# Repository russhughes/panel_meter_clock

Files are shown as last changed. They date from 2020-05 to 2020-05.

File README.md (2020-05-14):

Panel Meter Clock V2.1
----------------------
My father has been a lifelong Ham Radio Operator with a fondness for anything
with a panel meter. After seeing the [“Trinket Powered Analog Meter
Clock”](<https://learn.adafruit.com/trinket-powered-analog-meter-clock>) by
Mike and Anne Barela on the Adafruit website I knew I had to make one like it
to give to my Dad for his 80th birthday.

Here is Version 2.1 of that clock.

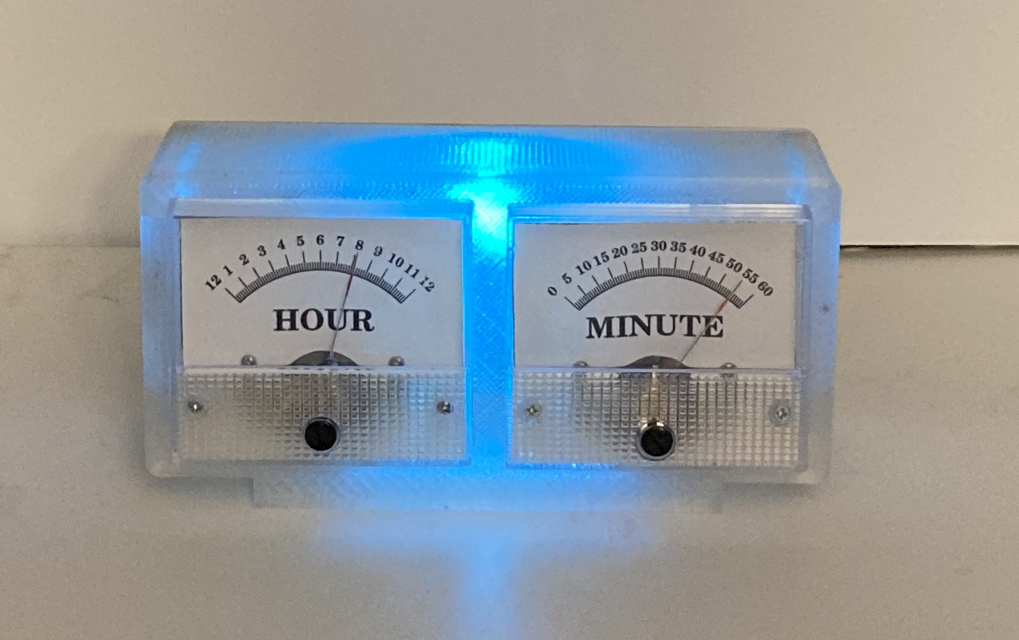
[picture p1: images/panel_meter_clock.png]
Panel Meter Clock


3D Printed Case
---------------
All parts print without support. I have printed them with 0.3mm or
0.2mm layer heights using 3 top, bottom and perimeter shells in PLA.

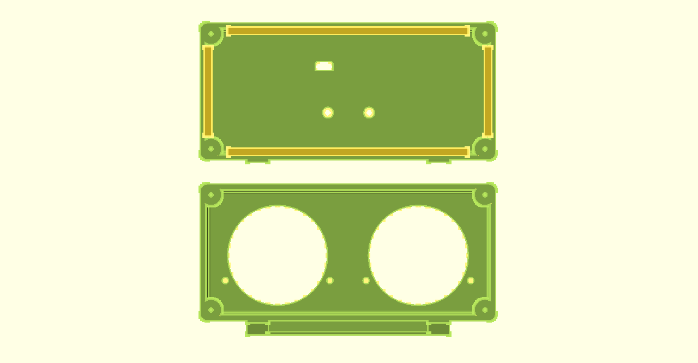
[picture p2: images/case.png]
Case


Meter Faces
-----------
The Hour and Minute meter scales were created using Inkscape. The source SVG
file is provided in case you wish to make changes, as well as 300 and 600dpi
PDF files that can be printed at 100% scale.

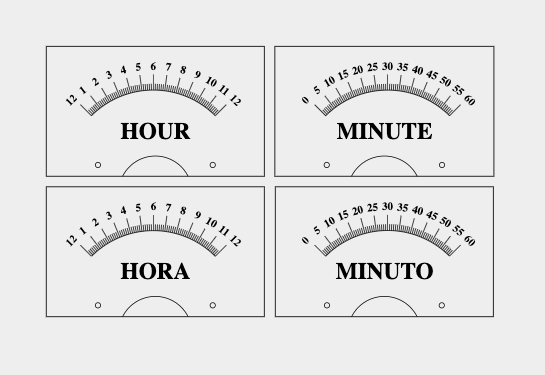
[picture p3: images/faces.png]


PC Board
--------
I designed a custom Arduino Leonardo compatible P.C. board with a DS321 RTC
clock, NeoPixel and USB connector that mounts directly to the back of the two
panel meters.

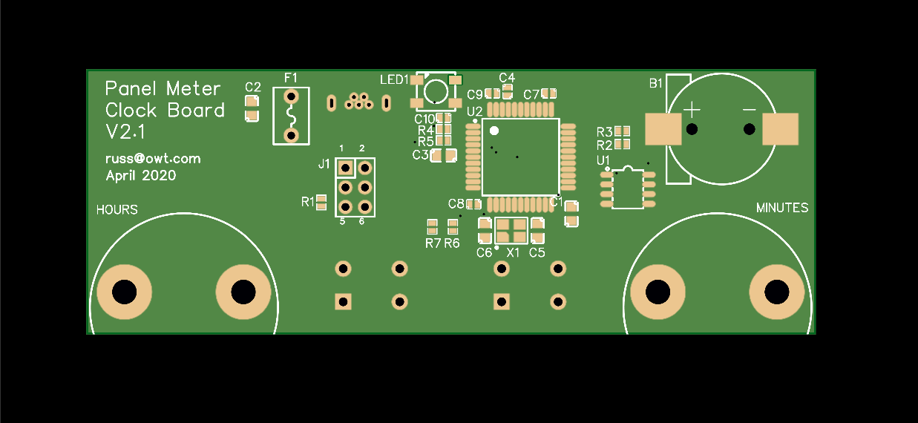
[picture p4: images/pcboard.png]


Additional Information
----------------------

[Assembly Video](https://youtu.be/PN79dx3BKjI)

[Assembly Instructions](http://penfold.owt.com/panel_meter_clock_v2.1)

[GitHub Repo](https://github.com/russhughes/panel_meter_clock)

Additional Arduino Libraries
----------------------------

- [Adafruit RTClib](https://github.com/adafruit/RTClib)
- [Adafruit NeoPixel](https://github.com/adafruit/Adafruit_NeoPixel)

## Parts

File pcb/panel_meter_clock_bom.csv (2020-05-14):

ID | Name | Designator | Footprint | Quantity | Manufacturer Part | Manufacturer | Supplier | Supplier Part | LCSC Assembly
1 | MINUTE_ADJ | MINUTE | SW4-6.0X6.0X5.0MM | 1 | TS-1109 |  | SeeedStudio | 311020024
2 | HOUR_ADJ | HOUR | SW4-6.0X6.0X5.0MM | 1 | TS-1109 |  | SeeedStudio | 311020024
3 | 22 | R5,R4 | R0402 | 2 | 0402WGF220JTCE | UniOhm | LCSC | C25092 | Yes
4 | 22pF | C6,C5 | C0603 | 2 | CL10C220JB8NNNC | SAMSUNG | LCSC | C1653 | Yes
5 | ATMEGA32U4-AU | U2 | QFP-44_L10.0-W10.0-P0.80-LS13.2-BL | 1 | ATMEGA32U4-AU | MICROCHIP | LCSC | C44854 | Yes
6 | DS3231MZ+ | U1 | SOIC-8_L4.9-W3.9-P1.27-LS6.0-BL | 1 | DS3231MZ+ | MAXIM | LCSC | C107410 | Yes
7 | 10uF | C2 | C0603 | 1 | CL10A106KP8NNNC | SAMSUNG | LCSC | C19702 | Yes
8 | WS2812B-B | LED1 | LED-SMD_4P-L5.0-W5.0-BL | 1 | WS2812B-B | Worldsemi | LCSC | C114586 | Yes
9 | 10K | R7,R6,R3,R2,R1 | R0402 | 5 | 0402WGF1002TCE | UniOhm | LCSC | C25744 | Yes
10 | ICSP | J1 | HEADER_PRG_2X03 | 1
11 | Voltmeter_DC | HOURS,MINUTES | 85C1 SERIES PANEL METER | 2
12 | micro 5P180 | USB | MICRO-USB-TH_U-MICRS05P-BF00 | 1 | micro 5P180 | ValuePro | LCSC | C40941
13 | TRC025 | F1 | FUSE-TH_L7.4-W4.6-P5.10-D0.6 | 1 | TRC025 | TLC Electronic | LCSC | C262081
14 | CR1220-2 | B1 | BAT-SMD_CR1220-2 | 1 | CR1220-2 | Q&J | LCSC | C70381
15 | 1uF | C1,C3 | C0603 | 2 | CL10A105KB8NNNC | SAMSUNG | LCSC | C15849 | Yes
16 | 100nF | C4,C9,C7,C10,C8 | C0402 | 5 | CL05B104KO5NNNC | SAMSUNG | LCSC | C1525 | Yes
17 | 16MHz | X1 | OSC-SMD_4P-L3.2-W2.5-BL | 1 | 7M1604LCSC-EEQ4S | TXC | LCSC | C90905 | Yes

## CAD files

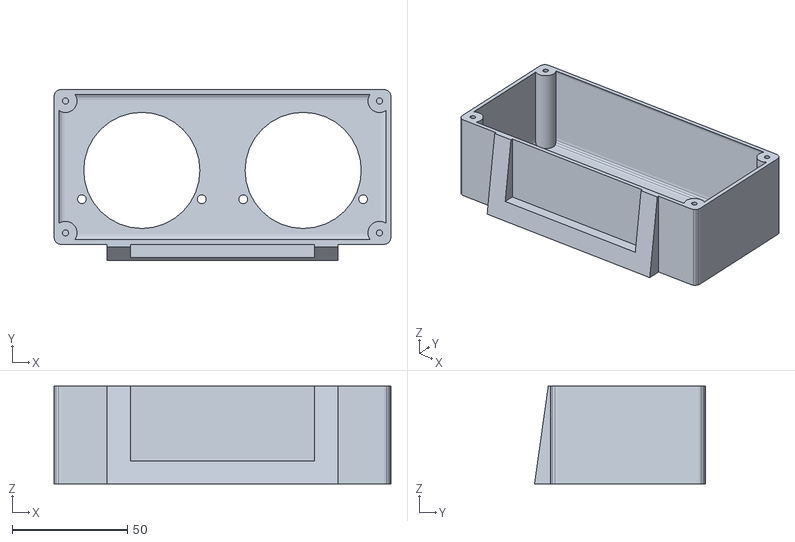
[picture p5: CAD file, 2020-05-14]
stl_files/panel_meter_clock_front.stl
146.2 x 74.2 x 42.4

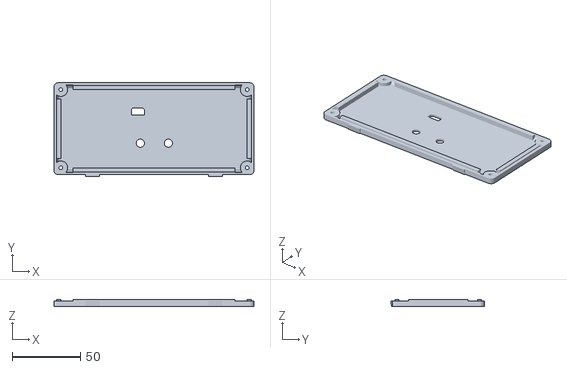
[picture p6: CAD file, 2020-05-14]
stl_files/panel_meter_clock_back.stl
146.2 x 68.4 x 5.00

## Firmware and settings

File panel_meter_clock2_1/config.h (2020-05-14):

//
// Panel Meter Clock by Russ Hughes (russ@owt.com)
// April 2020
//
//
// Shared under the Creative Commons - Attribution - ShareAlike 3.0 license.
//

#ifndef __CONFIG_H__
#define __CONFIG_H__

// define pins usage

#define HOURPWM 5
#define MINPWM  6
#define HOURADJ 8
#define MINADJ 11
#define NEOPIXEL 10

// EEPROM config value offsets

#define EEPROM_SENTINEL 0
#define EEPROM_HOURS_CAL 3
#define EEPROM_MINUTES_CAL 16
#define EEPROM_COLOR_MODE 138
#define EEPROM_GLOB_SCALE 139
#define EEPROM_GMT_OFFSET 140
#define EEPROM_DST_OBS 141
#define EEPROM_NEOPIXEL_R 142
#define EEPROM_NEOPIXEL_G 143
#define EEPROM_NEOPIXEL_B 144
#define EEPROM_LATITUDE 145
#define EEPROM_LONGITUDE 155
#define EEPROM_AVAIL 165

// colorModes

#define MODE_NONE 0
#define MODE_FIXED 1
#define MODE_WHEEL 2
#define MODE_SKY 3
#define MODE_SUN 4

//
// BEGIN DEFAULT CONFIG VALUES
//

#define DEFAULT_COLOR_MODE MODE_WHEEL
#define DEFAULT_GMT_OFFSET -8
#define DEFAULT_DST_OBSERVED 1
#define DEFAULT_LATITUDE "46.2087"
#define DEFAULT_LONGITUDE "-119.1199"
#define DEFAULT_R 32
#define DEFAULT_G 0
#define DEFAULT_B 0

//
// END DEFAULT CONFIG VALUES
//

#define MAX_LOC_LEN 10

extern char aLatitude[MAX_LOC_LEN+1];
extern char aLongitude[MAX_LOC_LEN+1];

extern uint8_t HOURS_CAL[13];
extern uint16_t MINUTES_CAL[61];
extern uint8_t colorMode;
extern uint8_t globScale;
extern int8_t gmtOffset;
extern uint8_t dstObs;
extern float longitude;
extern float latitude;

extern int dstActive;
extern int lastDay;
extern int lastHour;
extern int lastMinute;
extern int colorStep;
extern uint8_t r, g, b;

extern float sky_angle;
extern DateTime theTime;

extern Adafruit_NeoPixel pixel;
extern RTC_DS3231 rtc;

void configCreate();
void configLoad();
void configMenu();

extern int isDST(int day, int month, int dow);
extern DateTime now(void);

extern void setColor(uint32_t color);
extern uint32_t Wheel(byte WheelPos);
extern void setPixelColor(float sky_angle, uint8_t glob_scale);

#endif

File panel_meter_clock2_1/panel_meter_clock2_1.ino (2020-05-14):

//
// Panel Meter Clock by Russ Hughes (russ@owt.com)
// April 2020
//
// Shared under the Creative Commons - Attribution - ShareAlike 3.0 license.
//

#include <avr/pgmspace.h>
#include <EEPROM.h>
#include <RTClib.h>
#include <Adafruit_NeoPixel.h>
#include <stdint.h>
#include <math.h>

#include "config.h"

int dosetdate = 0;	// set to 1 to always set date/time to compiled time.

//
// Solar Calculations based on formulas from the NOAA Sunrise/Sunset and Solar Position
// Calculator Excel spreadsheet availabe from:
//
// https://www.esrl.noaa.gov/gmd/grad/solcalc/NOAA_Solar_Calculations_day.xls
//

#include "sun.h"

/*
 * colourcalc.h
 *
 * Created: 19/10/2016 15:06:02
 *  Author: David Brown
 * Shared under the Creative Commons - Attribution - ShareAlike 3.0 license.
 */

#include "colourcalc.h"
perez colour;

// Prototypes
float level(float in);

// Globals

float sky_angle = 1.309;
float theta_max;
float theta_sun;
float scalar = 3;
float turbidity = 1.8;

int dstActive = 0;
int	lastDay = -1;
int lastHour = -1;
int lastMinute = -1;
int colorStep = 0;

Adafruit_NeoPixel pixel = Adafruit_NeoPixel(1, NEOPIXEL, NEO_GRB + NEO_KHZ800);
RTC_DS3231 rtc;

//
// Returns 1 if DST should be active today
//

int isDST(int day, int month, int dow) {
   if (month < 3 || month > 11) {
      return 0;
   }
   if (month > 3 && month < 11) {
      return 1;
   }
   int previousSunday = day - dow;
   if (month == 3) {
      return previousSunday >= 8;
   }
   return previousSunday <= 0;
}

//
// Returns the current time as a DateTime object adjusting for
// US daylight saving time as needed if dstObs is set to a true value
//

DateTime now(void) {

    // get the time from the RTC
    DateTime theTime = rtc.now();

    // check if DST is observed in this location
    if (dstObs) {
        // check if DST should be in effect today
        if (isDST(theTime.day(), theTime.month(), theTime.dayOfTheWeek())) {
            // if DST is not currently active & it is after 02:00
            if (!dstActive && theTime.hour() >= 2)
                dstActive = 1;          // make DST active
        } else {
            // if DST is currently active & it is after 02:00
        if (dstActive && theTime.hour() >= 2)
            dstActive = 0;  // make DST not active
        }
    } else {
		dstActive = 0;	// DST not observed so not active
	}

	// if DST is active spring forward one hour
    if (dstActive)
        return theTime + TimeSpan(0, 1, 0, 0);

	// DST is not active use RTC time directly
	return theTime;
}

//
// Calculates the solar max using the height of the sun
// in radians at solar noon for the current day.
//

float calcSolarMax() {
	int solarNoonHour;
	int solarNoonMinute;

	theTime = now();
	float solarNoon = calcSolarNoon(
		latitude,
		longitude,
		theTime.year(),
		theTime.month(),
		theTime.day(),
		gmtOffset
	);

	decToHourMinute(solarNoon, &solarNoonHour, &solarNoonMinute);

	return radians(
		calcSolarZenithAngle(
			latitude,
			longitude,
			theTime.year(),
			theTime.month(),
			theTime.day(),
			solarNoonHour,
			solarNoonMinute,
			gmtOffset
		)
	);
}

//
// Setup IO pins, PWN, RTC and NeoPixel.
//

void setup() {
    Serial.begin(9600);

	// Check EEPROM for calibration data

	if (EEPROM[EEPROM_SENTINEL] != 'P' && EEPROM[EEPROM_SENTINEL+1] != 'M' &&EEPROM[EEPROM_SENTINEL+2] != 'C') {
		configCreate();
	}

	//configCreate();  // uncomment to override EEPROM settings with defaults
	configLoad();

    pinMode(HOURPWM, OUTPUT);	// hour pwm pin
    pinMode(MINPWM, OUTPUT);	// minute pwm pin
    pinMode(HOURADJ, INPUT);	// hour adjust pin
    pinMode(MINADJ, INPUT);		// minute adjust pin

	//
	// Set D6 to 10 bit PWM
	//

    TCCR4E |= (1<<ENHC4);
    TCCR4B &= ~(1<<CS41);
    TCCR4B |= (1<<CS42)|(1<<CS40);
    TCCR4D |= (1<<WGM40);
    TC4H = 0x3;
    OCR4C = 0xFF;
    TCCR4C |= (1<<COM4D1)|(1<<PWM4D);

	//
    // Start the clock
	//

    if (! rtc.begin()) {
		while(1) {
        	Serial.println(F("Could not find RTC!"));
			delay(1000);
		}
    }

	//
	// if the RTC lost power set the RTC to the date & time this sketch was compiled
	//

    if (dosetdate || rtc.lostPower()) {
        Serial.println(F("RTC was NOT running!"));
        rtc.adjust(DateTime(F(__DATE__), F(__TIME__)));
    }

	//
	// Get the solar max for today
	//

	theta_max = calcSolarMax();

	//
	// Start the NeoPixel
	//

    pixel.begin();
	if (colorMode == MODE_FIXED) {
		pixel.setPixelColor(0, pixel.Color(r, g, b));
		pixel.show();
	}

	//
	// Initialize the color class & coefficients
	//

	colour.generate_perez_coeff(turbidity);
}

//
//	Update minute meter 10 bit PWM
//

void updateMinute(uint16_t value) {
	TC4H = value>>8;
    OCR4D = (value&0xFF);
}

//
//  Sets the NeoPixel color
//

void setColor(uint32_t color) {
   	pixel.setPixelColor(0, color);
   	pixel.show();
}

//
// Return the color for the given WheelPos
//

uint32_t Wheel(byte WheelPos) {
    WheelPos = 255 - WheelPos;
    if (WheelPos < 85) {
        return pixel.Color(255 - WheelPos * 3, 0, WheelPos * 3);
    }
    if (WheelPos < 170) {
        WheelPos -= 85;
        return pixel.Color(0, WheelPos * 3, 255 - WheelPos * 3);
    }
    WheelPos -= 170;
    return pixel.Color(WheelPos * 3, 255 - WheelPos * 3, 0);
}

//
// Main Loop
//

void loop() {

	int day;
    int	hour;
    int minute;

	//
	//	Bring up the configure menu if the
	//	escape key is pressed
	//

	if (Serial.available()) {
		char ch = Serial.read();
		if (ch == 27)
			configMenu();
	}

	//
	//	Advance the hour if the hour adjust button
	// 	is pressed and released
	//

    if (digitalRead(HOURADJ) == LOW)  {
        while (digitalRead(HOURADJ) == LOW)
            delay(50);

        rtc.adjust(rtc.now() + TimeSpan(0, 1, 0, 0));
    }

	//
	//	Advance the minute if the minute adjust button
	// 	is pressed and released
	//

    if (digitalRead(MINADJ) == LOW)  {
        while (digitalRead(MINADJ) == LOW)
            delay(50);

        rtc.adjust(rtc.now() + TimeSpan(0, 0, 1, 0));
    }

	//
	// Get the current time
	//

    theTime = now();

    hour = theTime.twelveHour();
    if (hour == 12)
    	hour = 0;

    minute = theTime.minute();

    //
    // if the day has changed
    //  calculate the solar max for the day
    //

	day = theTime.day();
	if (day != lastDay) {
		theta_max = calcSolarMax();
		lastDay = day;
	}

	//
	// if the hour has changed update the hour meter,
	//		sweep the meter back if last hour was 12
	//

    if (hour != lastHour) {
        if (lastHour == 12) {
            for (int i = lastHour; i != 0; i--) {
                analogWrite(HOURPWM, HOURS_CAL[i]);
                delay(1000 / 12);
            }
        }
        else
            analogWrite(HOURPWM, HOURS_CAL[hour]);

        lastHour = hour;
    }

	//
	// if the minute has changed update the minute meter,
	//		sweep the meter back if last minute was 59
	//

    if (minute != lastMinute) {
        if (lastMinute == 59) {
            for (int i = lastMinute; i != 0; i--) {
                updateMinute(MINUTES_CAL[i]);
                delay(1000 / 59);
            }
        }
        else
            updateMinute(MINUTES_CAL[minute]);

        lastMinute = minute;

        // Update the NeoPixel color

    	if (colorMode == MODE_SUN) {
    		setPixelColor(sky_angle, 255);
    	} else if (colorMode == MODE_SKY) {
    		setPixelColor(sky_angle-(M_PI/2), 255);
    	}
    }

	//
	//	Step the NeoPixel color to the next color
	//		and wait 100ms
	//

	if (colorMode == MODE_WHEEL) {
    	colorStep++;
    	colorStep %= 255;
    	pixel.setPixelColor(0, Wheel(colorStep));
    	pixel.show();
	}

    delay(100);
}

//
// calculate and set the NeoPixel color
//
// color calculation code based on:
//
// Sunrise_v10-AVR.cpp
// Created: 19/10/2016 10:17:11
// Author : David Brown
// Shared under the Creative Commons - Attribution - ShareAlike 3.0 license.
//

float level(float in)
{
	if (in <= 0)
		return 0.0;

	return in;
}

void setPixelColor(float sky_angle, uint8_t glob_scale)
{
	RGB_value f_value;
    float theta_sun;
    float gamma = 1/1.8;

	theta_sun = radians(
		calcSolarZenithAngle(
			latitude,
			longitude,
			theTime.year(),
			theTime.month(),
			theTime.day(),
			theTime.hour(),
			theTime.minute(),
			gmtOffset
		)
	);

	//check theta sun is valid, cant be less than max theta and 360 deg - max theta
	if (theta_sun < theta_max || theta_sun > ((2*M_PI)-theta_max)) {
		theta_sun = 3;
	}

	// scalar function pulled output to zero when sun below civic twilight and then uses
	// cosine distribution to scale the intensity from current to maximum sun angle (midday)

	scalar = level(cos((theta_sun-theta_max)*1.5));
	f_value = colour.calc_RGB_out(theta_sun*0.01745329252, sky_angle, turbidity);
	f_value.R = (pow(level(f_value.R),(gamma))*scalar);
	f_value.G = (pow(level(f_value.G),(gamma))*scalar);
	f_value.B = (pow(level(f_value.B),(gamma))*scalar);

	r = (uint8_t)(f_value.R*glob_scale);
	g = (uint8_t)(f_value.G*glob_scale);
	b = (uint8_t)(f_value.B*glob_scale);

  	pixel.setPixelColor(0, pixel.Color(r, g, b));
    pixel.show();
}

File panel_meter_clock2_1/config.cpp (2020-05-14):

//
// Panel Meter Clock by Russ Hughes (russ@owt.com)
// April 2020
//
// Shared under the Creative Commons - Attribution - ShareAlike 3.0 license.
//

#include <Arduino.h>
#include <avr/pgmspace.h>
#include <EEPROM.h>
#include <RTClib.h>
#include <Adafruit_NeoPixel.h>

#include "config.h"

extern void updateMinute(uint16_t value);

//
// global configuration values
//

uint8_t HOURS_CAL[13] = {
    8, 27, 45, 64, 82, 102, 119, 136, 154, 171, 190, 207, 227
};

uint16_t MINUTES_CAL[61] = {
      96,  129,  162,  195,  228,  264,  296,  328,  360,  392,
     428,  460,  492,  524,  556,  590,  622,  654,  686,  718,
     754,  785,  816,  847,  878,  911,  943,  975, 1007, 1039,
    1074, 1105, 1136, 1167, 1198, 1232, 1262, 1292, 1322, 1352,
    1386, 1415, 1444, 1473, 1502, 1535, 1564, 1593, 1622, 1651,
    1684, 1714, 1744, 1774, 1804, 1838, 1868, 1898, 1928, 1958,
    1988
};

uint8_t globScale = 255;

uint8_t colorMode = DEFAULT_COLOR_MODE;
int8_t gmtOffset = DEFAULT_GMT_OFFSET;
uint8_t dstObs = DEFAULT_DST_OBSERVED;

uint8_t r = DEFAULT_R;
uint8_t g = DEFAULT_G;
uint8_t b = DEFAULT_B;

char aLatitude[MAX_LOC_LEN+1];
char aLongitude[MAX_LOC_LEN+1];

float longitude;
float latitude;

DateTime theTime;

//
// resetTimeFlags:
//	used when time or settings are changed
//

void resetTimeFlags() {
	lastDay = -1;
	lastHour = -1;
	lastMinute = -1;
	colorStep = 0;
}

//
// Load calibration data from EEPROM
//

void configLoad() {
	for (uint8_t val = 0; val < 13; val++) {
		EEPROM.get(val + EEPROM_HOURS_CAL, HOURS_CAL[val]);
	}

	for (uint8_t val = 0; val < 61; val++) {
		EEPROM.get(val*2 + EEPROM_MINUTES_CAL, MINUTES_CAL[val]);
	}

	EEPROM.get(EEPROM_COLOR_MODE, colorMode);
	EEPROM.get(EEPROM_GLOB_SCALE, globScale);
    EEPROM.get(EEPROM_GMT_OFFSET, gmtOffset);
    EEPROM.get(EEPROM_DST_OBS, dstObs);
    EEPROM.get(EEPROM_NEOPIXEL_R, r);
	EEPROM.get(EEPROM_NEOPIXEL_G, g);
	EEPROM.get(EEPROM_NEOPIXEL_B, b);

	for (int addr=0; addr < MAX_LOC_LEN; addr++) {
		aLatitude[addr] = EEPROM[EEPROM_LATITUDE+addr];
		aLongitude[addr] = EEPROM[EEPROM_LONGITUDE+addr];
	}

	aLatitude[EEPROM_LATITUDE+MAX_LOC_LEN+1] = 0;
	aLongitude[EEPROM_LONGITUDE+MAX_LOC_LEN+1] = 0;

	latitude = atof(aLatitude);
	longitude = atof(aLongitude);
}

//
// Save calibration data to EEPROM after calculating values between 5 minute marks
// and print C code for the default values that can be used in this program.
//

void configSave() {
	// calculate values between 5 minute marks

	for (int val = 5; val < 61; val +=5) {
		int first = MINUTES_CAL[val-5];
		int difference = MINUTES_CAL[val] - first;
		int step = difference / 5;

		for (int tick = 1; tick < 5; tick++) {
			MINUTES_CAL[val+tick-5] = first + step * tick;
		}
	}

	EEPROM[EEPROM_SENTINEL]   = 'P';
	EEPROM[EEPROM_SENTINEL+1] = 'M';
	EEPROM[EEPROM_SENTINEL+2] = 'C';

	Serial.println();
	Serial.println(F("// Your calibration values are:"));
	Serial.println();
	Serial.println(F("uint8_t HOURS_CAL[13] = {"));
	Serial.print(F("    "));

	for (int val = 0; val < 13; val++) {
		EEPROM.put(val + EEPROM_HOURS_CAL, HOURS_CAL[val]);
		Serial.print(HOURS_CAL[val]);
		if (val < 12)
			Serial.print(", ");
	}


	Serial.println();
	Serial.println("};");
	Serial.println();
	Serial.println(F("int MINUTES_CAL[61] = {"));
	Serial.print(F("    "));

	for (int val = 0; val < 61; val++) {
		EEPROM.put(EEPROM_MINUTES_CAL + val*2, MINUTES_CAL[val]);


		if (MINUTES_CAL[val] < 1000)
			Serial.print(" ");
		if (MINUTES_CAL[val] < 100)
			Serial.print(" ");

		Serial.print(MINUTES_CAL[val]);
		if (val < 60)
			Serial.print(", ");

		if (val && (val+1) % 10 == 0) {
			Serial.println();
			Serial.print(F("    "));
		}

	}

	Serial.println();
	Serial.println("};");

	EEPROM.put(EEPROM_COLOR_MODE, colorMode);
	EEPROM.put(EEPROM_GLOB_SCALE, globScale);
    EEPROM.put(EEPROM_GMT_OFFSET, gmtOffset);
    EEPROM.put(EEPROM_DST_OBS, dstObs);
    EEPROM.put(EEPROM_NEOPIXEL_R, r);
	EEPROM.put(EEPROM_NEOPIXEL_G, g);
	EEPROM.put(EEPROM_NEOPIXEL_B, b);

	for (int addr=0; addr < MAX_LOC_LEN; addr++) {
		EEPROM[EEPROM_LATITUDE+addr] = aLatitude[addr];
		EEPROM[EEPROM_LONGITUDE+addr] = aLongitude[addr];
	}
}

//
// Create EEPROM calibration data from constants.
//

void configCreate() {
//	Serial.println(F("Creating EEPROM calibration data using default data."));

	memset(aLatitude, 0, MAX_LOC_LEN+1);
	memset(aLongitude, 0, MAX_LOC_LEN+1);

	strncpy(aLatitude, DEFAULT_LATITUDE, MAX_LOC_LEN);
	strncpy(aLongitude, DEFAULT_LONGITUDE, MAX_LOC_LEN);

	configSave();
}

//
//	helper routine to calculate EEPROM offsets.
//
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
